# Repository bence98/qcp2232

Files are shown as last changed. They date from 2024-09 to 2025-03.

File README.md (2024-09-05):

# QCP2232HV USB-to-Quad UART

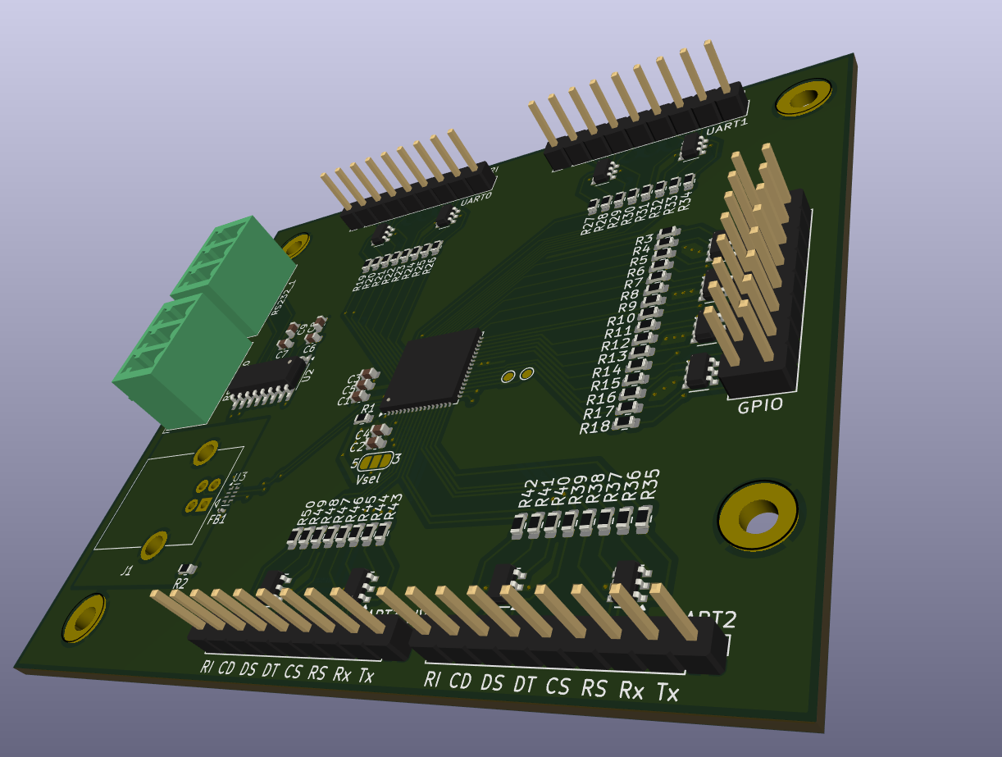
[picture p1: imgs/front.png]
Front side

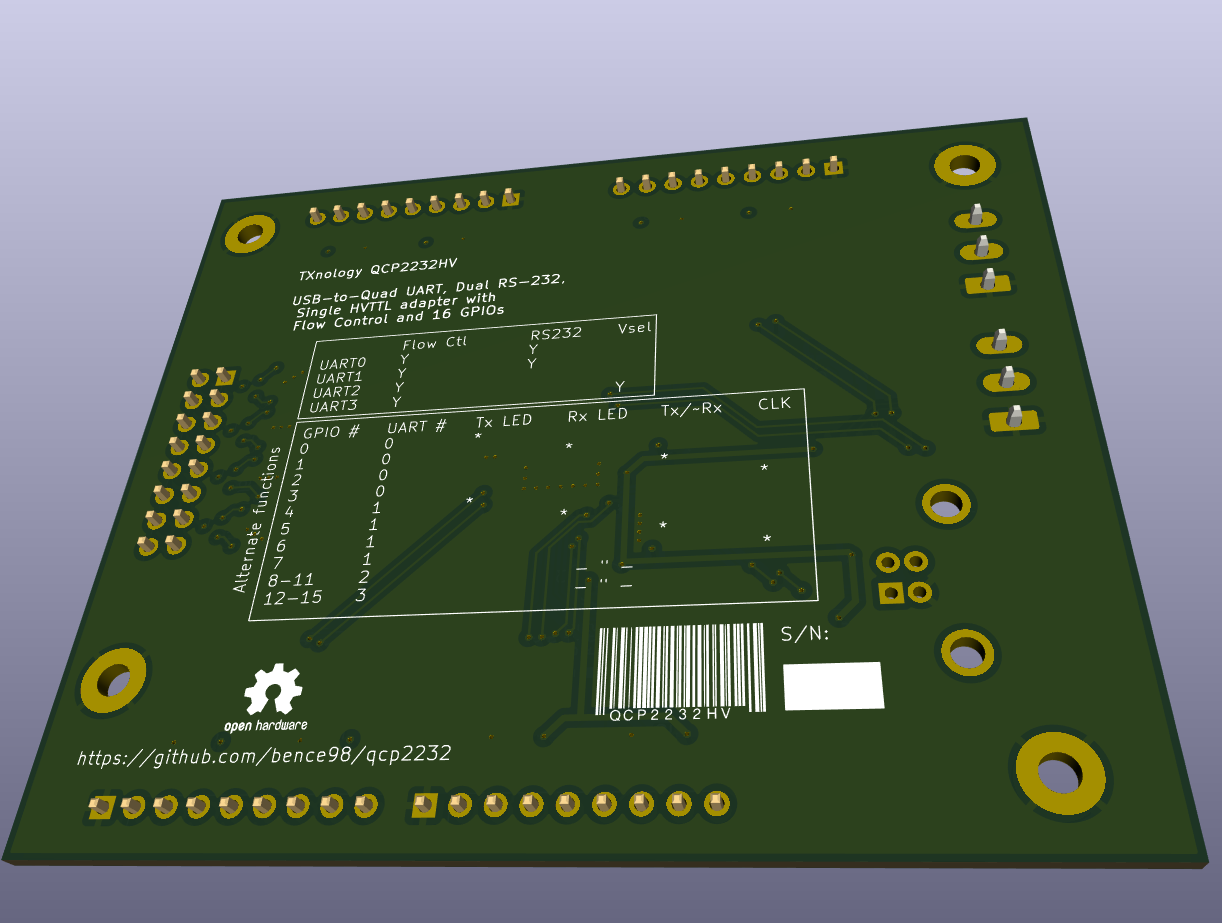
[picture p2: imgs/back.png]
Back side


## Features

4 TTL UARTs with full Flow Control
* Tx, Rx full duplex
* RTS/CTS (Request-/Clear-to-Send), DTR/DSR (Data Terminal/Set Ready)
* DCD (Data Carrier Detect), RI (Ring Indicator) inputs
* all pins ESD protected
  * full TVS diode protection
  * overcurrent limiting resistors
* see pinout at the end of the section

UART0 and UART1 have RS-232 option
* only Tx/Rx
* separate industrial connector
  * Phoenix MCV 1,5 G-3.81
  * Würth WR-TBL 321

UART3 has selectable TTL voltage (`Vsel`)
* 5V from USB or 3.3V from internal regulator
* UART0-2 are 3.3V

USB Type-B connector
* superior mechanical stability compared to Micro-B
* easier to handle than Mini-B
* more economical to produce than Type-C
* added noise immunity thanks to EMI suppression circuitry
* supports USB suspend mode

16 GPIOs
* 3.3V digital I/O
* all pins ESD protected
  * full TVS diode protection
  * overcurrent limiting resistors
* alternate functions, see table below
  * Tx, Rx LED: blinks on data transfer
  * Tx mode: for half duplex bus drivers eg. RS-485
  * clock: USART bit clock
* configurable via Silicon Labs' toolchain

| GPIO # | UART # | function |
|---|---|---|
| 0 | 0 | Tx LED |
| 1 | 0 | Rx LED |
| 2 | 0 |  Tx mode |
| 3 | 0 | clock |
| 4 | 1 | Tx LED |
| 5 | 1 | Rx LED |
| 6 | 1 |  Tx mode |
| 7 | 1 | clock |
| 8 | 2 | Tx LED |
| 9 | 2 | Rx LED |
| 10 | 2 |  Tx mode |
| 11 | 2 | clock |
| 12 | 3 | Tx LED |
| 13 | 3 | Rx LED |
| 14 | 3 |  Tx mode |
| 15 | 3 | clock |

Pinout (UARTs):

| | GND | TX  | RX | RTS | CTS | DTR | DSR | DCD | RI |
|---|-----|-----|----|-----|-----|-----|-----|-----|----|
| Label on board | | Tx  | Rx | RS  | CS  | DT  | DS  | CD  | RI |
| Direction | N/A | Out | In | Out | In  | Out | In  | In  | In |

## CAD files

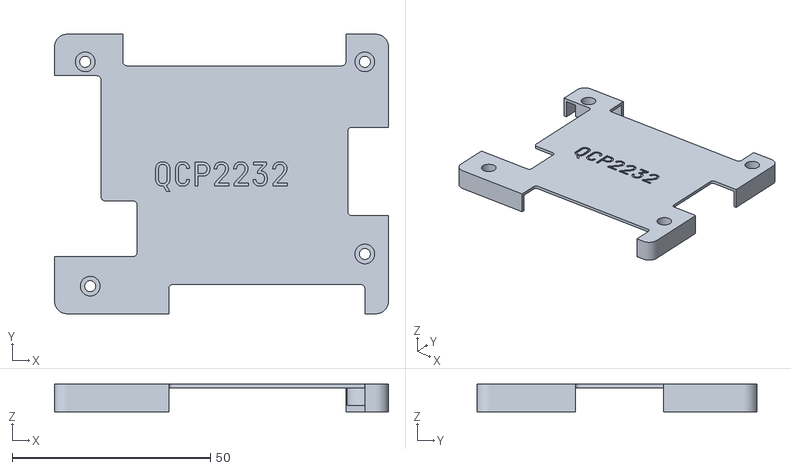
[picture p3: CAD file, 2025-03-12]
case/QCP2232 v5 top.stl
84.3 x 70.6 x 7.00

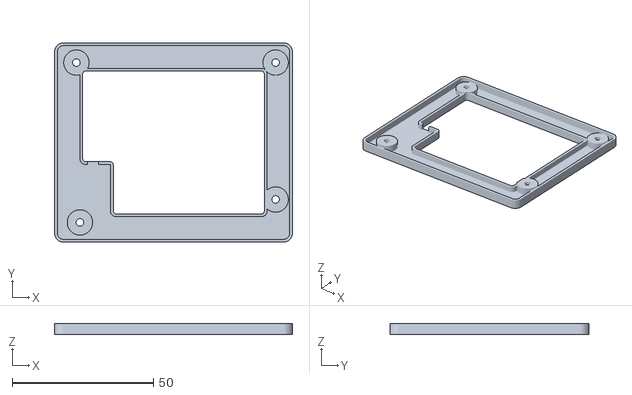
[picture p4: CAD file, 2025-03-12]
case/QCP2232 v5 bottom.stl
84.3 x 70.6 x 4.00

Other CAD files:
case/QCP2232 v6.f3z

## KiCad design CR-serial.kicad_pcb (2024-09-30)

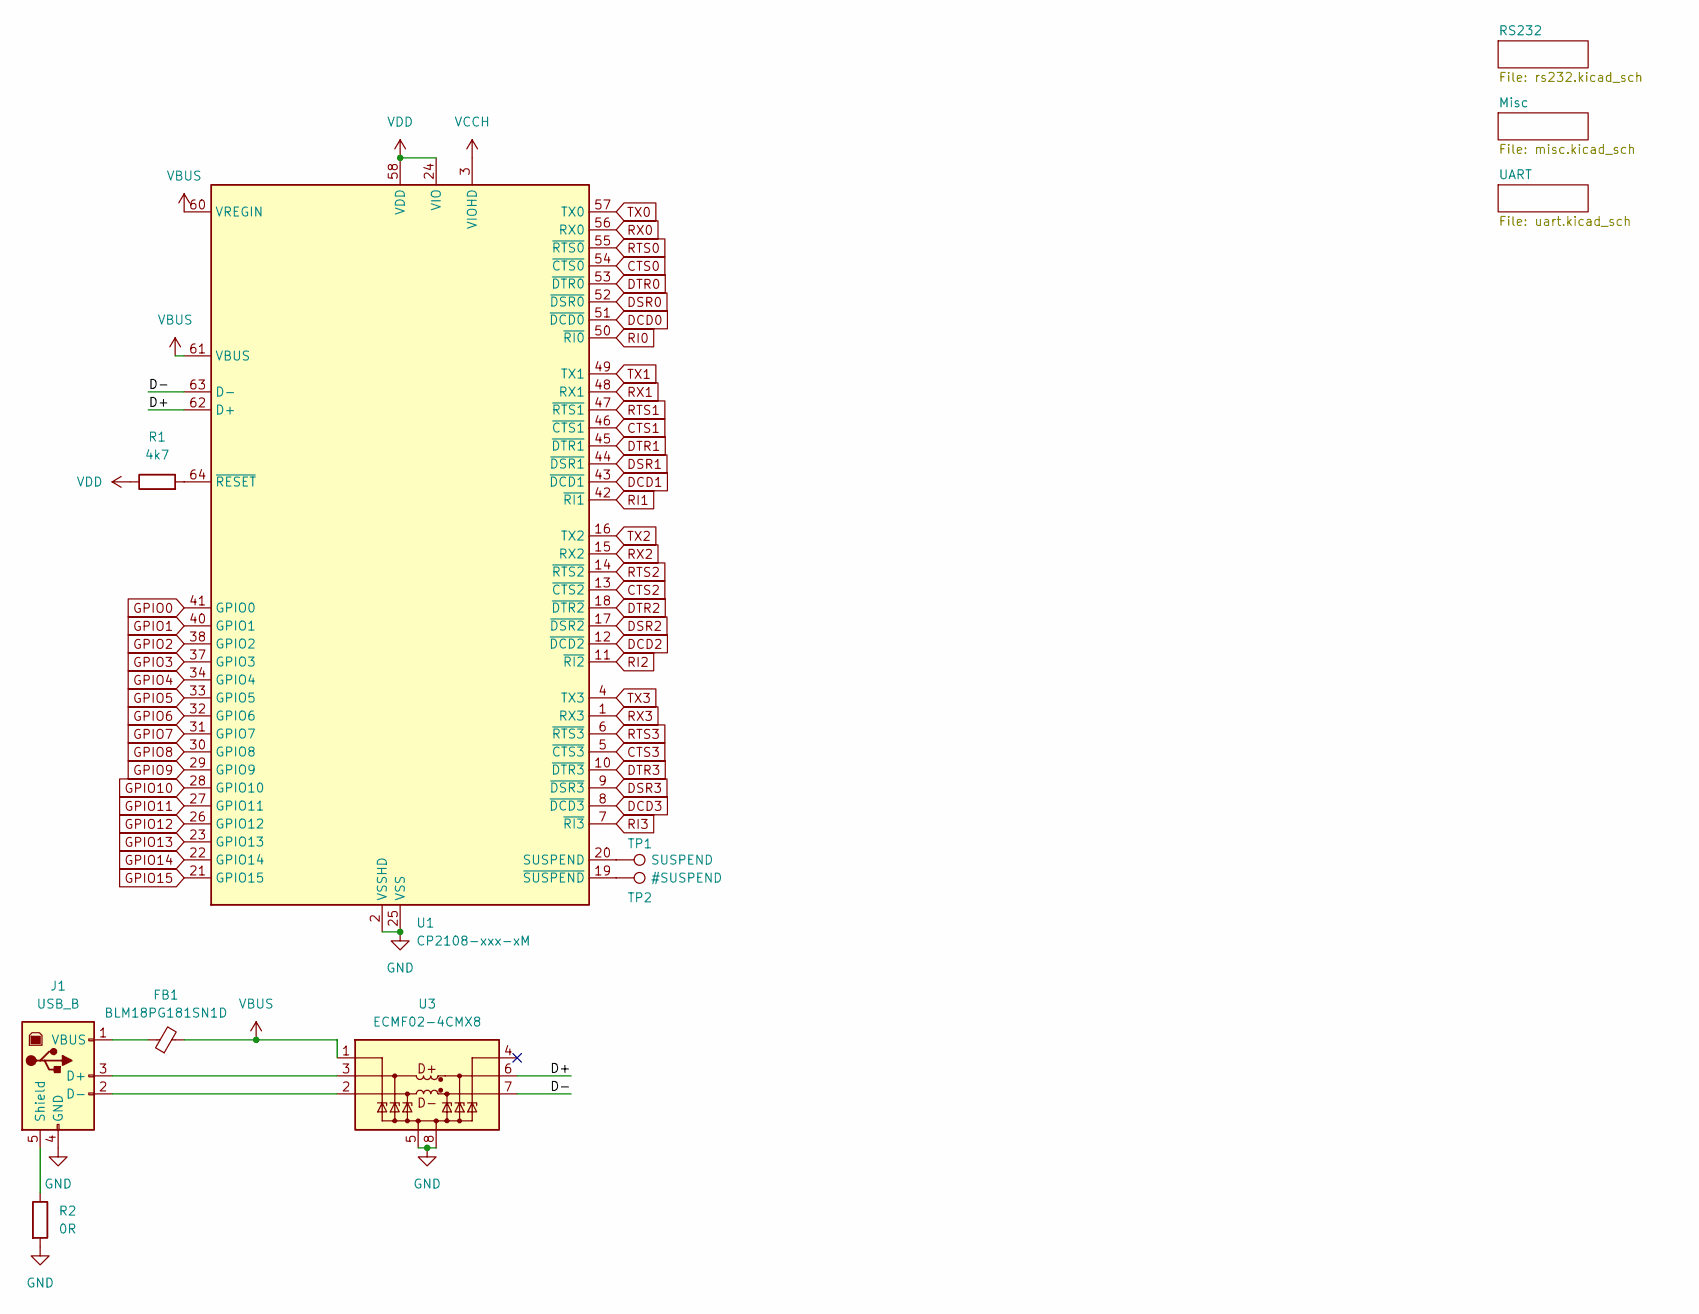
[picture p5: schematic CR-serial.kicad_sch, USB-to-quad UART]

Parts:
FB1: BLM18PG181SN1D; L_0603_1608Metric
J1: USB_B; USB_B_OST_USB-B1HSxx_Horizontal
R1: 4k7; R_0603_1608Metric
R2: 0R; R_0603_1608Metric
TP1: SUSPEND; TestPoint_Pad_D1.0mm
TP2: #SUSPEND; TestPoint_Pad_D1.0mm
U1: CP2108-xxx-xM; QFN-64-1EP_9x9mm_P0.5mm_EP4.1x4.1mm
U3: ECMF02-4CMX8; ST_UQFN-8L_1.15x2.45mm_P0.5mm

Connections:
/D+: U1.62 (D+), U3.6 (D+_out)
/D-: U1.63 (D-), U3.7 (D-_out)
CTS0: U1.54 (~CTS0); also elsewhere on the board
CTS1: U1.46 (~CTS1); also elsewhere on the board
CTS2: U1.13 (~CTS2); also elsewhere on the board
CTS3: U1.5 (~CTS3); also elsewhere on the board
DCD0: U1.51 (~DCD0); also elsewhere on the board
DCD1: U1.43 (~DCD1); also elsewhere on the board
DCD2: U1.12 (~DCD2); also elsewhere on the board
DCD3: U1.8 (~DCD3); also elsewhere on the board
DSR0: U1.52 (~DSR0); also elsewhere on the board
DSR1: U1.44 (~DSR1); also elsewhere on the board
DSR2: U1.17 (~DSR2); also elsewhere on the board
DSR3: U1.9 (~DSR3); also elsewhere on the board
DTR0: U1.53 (~DTR0); also elsewhere on the board
DTR1: U1.45 (~DTR1); also elsewhere on the board
DTR2: U1.18 (~DTR2); also elsewhere on the board
DTR3: U1.10 (~DTR3); also elsewhere on the board
GND: J1.4 (GND), R2.2, U1.2 (VSSHD), U1.25 (VSS), U1.59 (VSS), U1.65 (VSS), U3.5 (GND), U3.8 (GND); also elsewhere on the board
GPIO0: U1.41 (GPIO0); also elsewhere on the board
GPIO1: U1.40 (GPIO1); also elsewhere on the board
GPIO2: U1.38 (GPIO2); also elsewhere on the board
GPIO3: U1.37 (GPIO3); also elsewhere on the board
GPIO4: U1.34 (GPIO4); also elsewhere on the board
GPIO5: U1.33 (GPIO5); also elsewhere on the board
GPIO6: U1.32 (GPIO6); also elsewhere on the board
GPIO7: U1.31 (GPIO7); also elsewhere on the board
GPIO8: U1.30 (GPIO8); also elsewhere on the board
GPIO9: U1.29 (GPIO9); also elsewhere on the board
GPIO10: U1.28 (GPIO10); also elsewhere on the board
GPIO11: U1.27 (GPIO11); also elsewhere on the board
GPIO12: U1.26 (GPIO12); also elsewhere on the board
GPIO13: U1.23 (GPIO13); also elsewhere on the board
GPIO14: U1.22 (GPIO14); also elsewhere on the board
GPIO15: U1.21 (GPIO15); also elsewhere on the board
unnamed: J1.3 (D+), U3.3 (D+_in)
unnamed: J1.2 (D-), U3.2 (D-_in)
unnamed: J1.5 (Shield), R2.1
unnamed: FB1.1, J1.1 (VBUS)
unnamed: TP1.1, U1.20 (SUSPEND)
unnamed: R1.2, U1.64 (~RESET)
unnamed: TP2.1, U1.19 (~SUSPEND)
RI0: U1.50 (~RI0); also elsewhere on the board
RI1: U1.42 (~RI1); also elsewhere on the board
RI2: U1.11 (~RI2); also elsewhere on the board
RI3: U1.7 (~RI3); also elsewhere on the board
RTS0: U1.55 (~RTS0); also elsewhere on the board
RTS1: U1.47 (~RTS1); also elsewhere on the board
RTS2: U1.14 (~RTS2); also elsewhere on the board
RTS3: U1.6 (~RTS3); also elsewhere on the board
RX0: U1.56 (RX0); also elsewhere on the board
RX1: U1.48 (RX1); also elsewhere on the board
RX2: U1.15 (RX2); also elsewhere on the board
RX3: U1.1 (RX3); also elsewhere on the board
TX0: U1.57 (TX0); also elsewhere on the board
TX1: U1.49 (TX1); also elsewhere on the board
TX2: U1.16 (TX2); also elsewhere on the board
TX3: U1.4 (TX3); also elsewhere on the board
VBUS: FB1.2, U1.60 (VREGIN), U1.61 (VBUS), U3.1 (VBUS); also elsewhere on the board
VCCH: U1.3 (VIOHD); also elsewhere on the board
VDD: R1.1, U1.24 (VIO), U1.39 (VIO), U1.58 (VDD); also elsewhere on the board

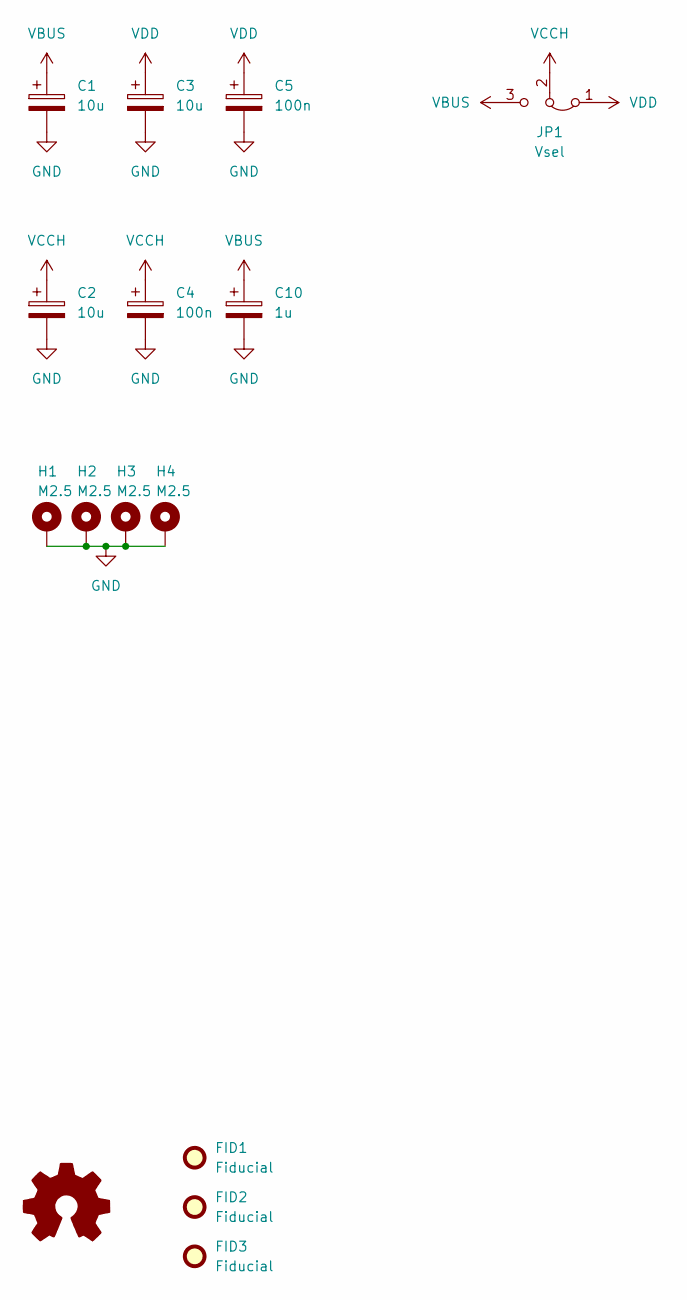
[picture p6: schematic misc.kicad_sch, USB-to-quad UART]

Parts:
C1, C2, C3: 10u; C_0603_1608Metric
C4, C5: 100n; C_0603_1608Metric
C10: 1u; C_0603_1608Metric
FID1, FID2, FID3: Fiducial; Fiducial_Cross_0.5mm_Mask2mm
H1, H2, H3, H4: M2.5; MountingHole_2.7mm_M2.5_Pad
JP1: Vsel; SolderJumper-3_P1.3mm_Bridged12_RoundedPad1.0x1.5mm_NumberL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
SYM1: Logo_Open_Hardware_Small; OSHW-Logo2_7.3x6mm_SilkScreen

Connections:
GND: C1.2, C2.2, C3.2, C4.2, C5.2, C10.2, H1.1, H2.1, H3.1, H4.1; also elsewhere on the board
VBUS: C1.1, C10.1, JP1.3 (B); also elsewhere on the board
VCCH: C2.1, C4.1, JP1.2 (C); also elsewhere on the board
VDD: C3.1, C5.1, JP1.1 (A); also elsewhere on the board

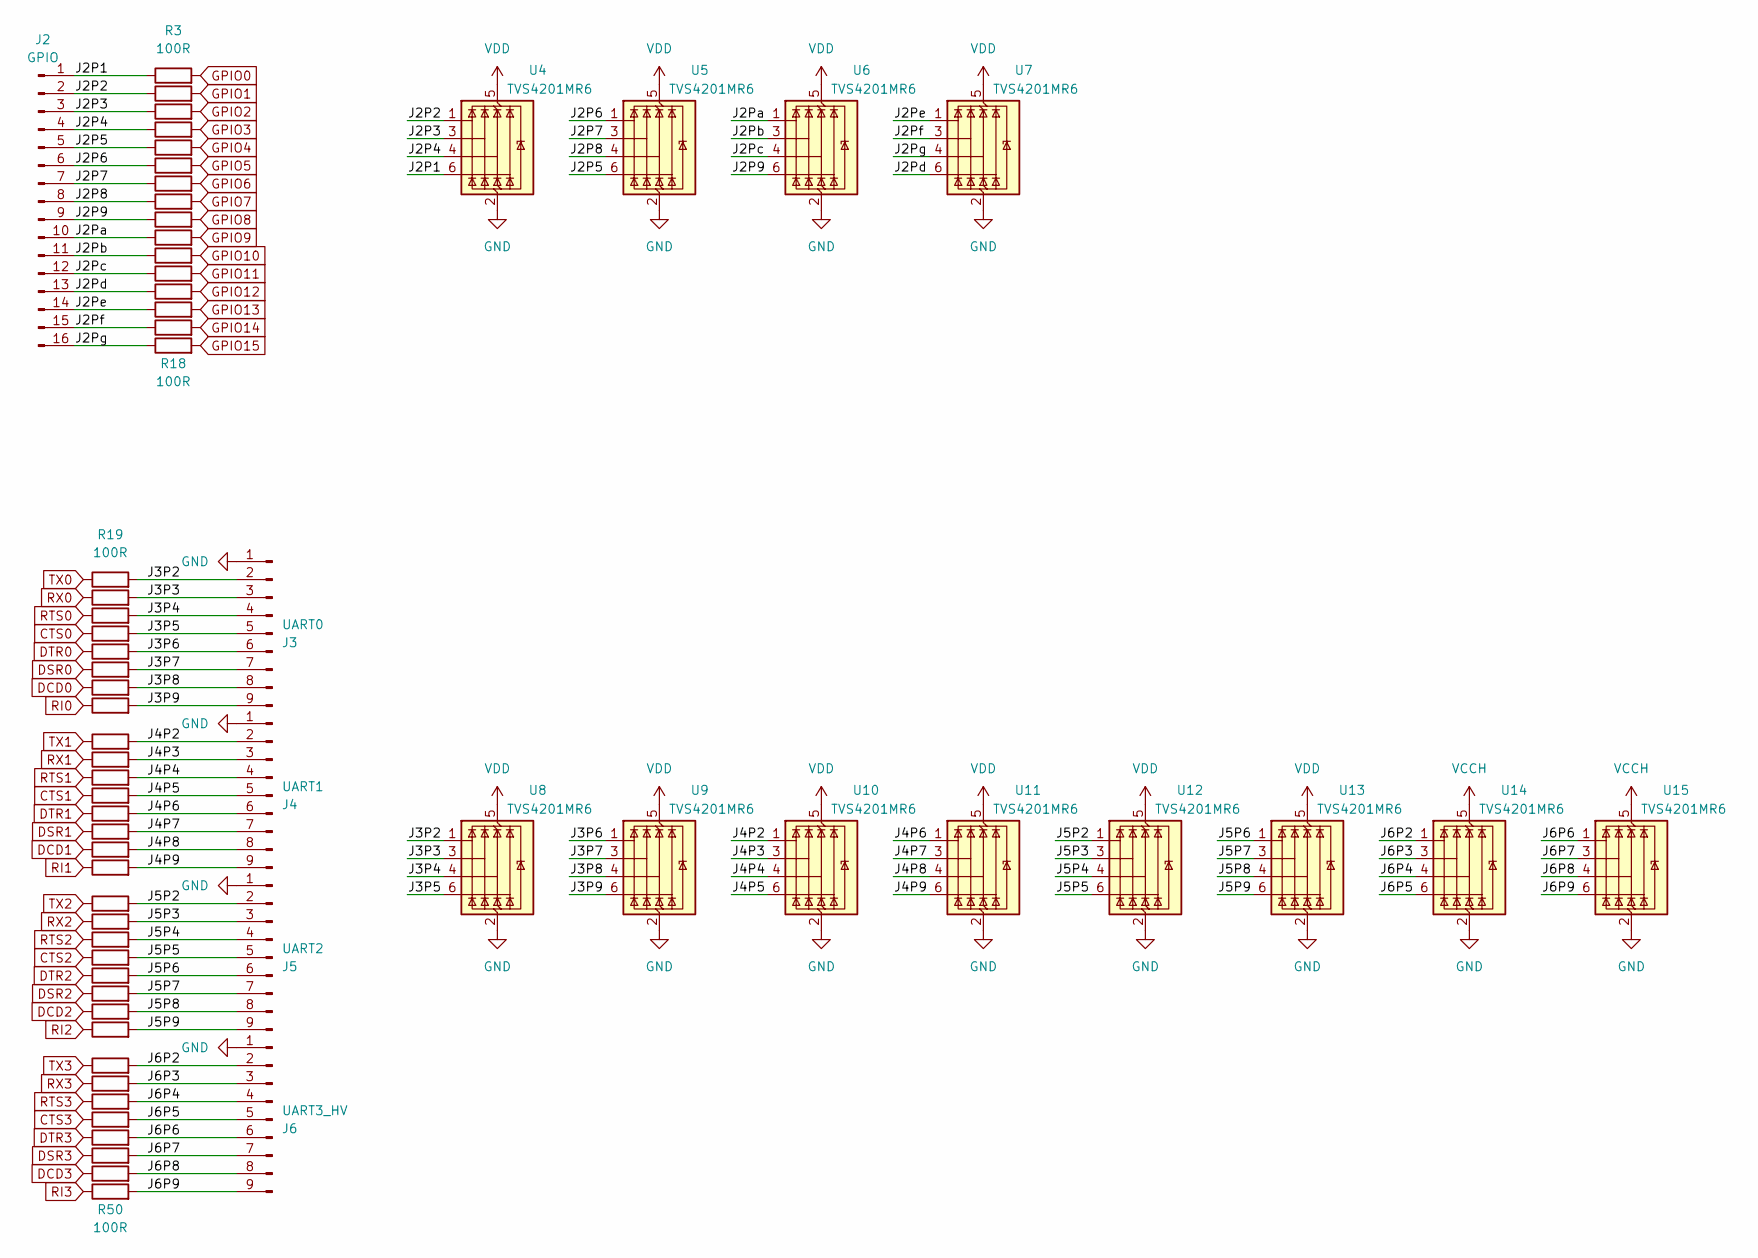
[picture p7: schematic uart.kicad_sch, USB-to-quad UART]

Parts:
J2: GPIO; PinHeader_2x08_P2.54mm_Vertical
J3: UART0; PinHeader_1x09_P2.54mm_Vertical
J4: UART1; PinHeader_1x09_P2.54mm_Vertical
J5: UART2; PinHeader_1x09_P2.54mm_Vertical
J6: UART3_HV; PinHeader_1x09_P2.54mm_Vertical
R3, R4, R5, R6, R7, R8, R9, R10, R11, R12, R13, R14, R15, R16, R17, R18, R19, R20, R21, R22, R23, R24, R25, R26, R27, R28, R29, R30, R31, R32, R33, R34, R35, R36, R37, R38, R39, R40, R41, R42, R43, R44, R45, R46, R47, R48, R49, R50: 100R; R_0603_1608Metric
U4, U5, U6, U7, U8, U9, U10, U11, U12, U13, U14, U15: TVS4201MR6; TSOP-6_1.65x3.05mm_P0.95mm

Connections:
/UART/J2P1: J2.1, R3.1, U4.6 (I/O4)
/UART/J2P2: J2.2, R4.1, U4.1 (I/O1)
/UART/J2P3: J2.3, R5.1, U4.3 (I/O2)
/UART/J2P4: J2.4, R6.1, U4.4 (I/O3)
/UART/J2P5: J2.5, R7.1, U5.6 (I/O4)
/UART/J2P6: J2.6, R8.1, U5.1 (I/O1)
/UART/J2P7: J2.7, R9.1, U5.3 (I/O2)
/UART/J2P8: J2.8, R10.1, U5.4 (I/O3)
/UART/J2P9: J2.9, R11.1, U6.6 (I/O4)
/UART/J2Pa: J2.10, R12.1, U6.1 (I/O1)
/UART/J2Pb: J2.11, R13.1, U6.3 (I/O2)
/UART/J2Pc: J2.12, R14.1, U6.4 (I/O3)
/UART/J2Pd: J2.13, R15.1, U7.6 (I/O4)
/UART/J2Pe: J2.14, R16.1, U7.1 (I/O1)
/UART/J2Pf: J2.15, R17.1, U7.3 (I/O2)
/UART/J2Pg: J2.16, R18.1, U7.4 (I/O3)
/UART/J3P2: J3.2, R19.2, U8.1 (I/O1)
/UART/J3P3: J3.3, R20.2, U8.3 (I/O2)
/UART/J3P4: J3.4, R21.2, U8.4 (I/O3)
/UART/J3P5: J3.5, R22.2, U8.6 (I/O4)
/UART/J3P6: J3.6, R23.2, U9.1 (I/O1)
/UART/J3P7: J3.7, R24.2, U9.3 (I/O2)
/UART/J3P8: J3.8, R25.2, U9.4 (I/O3)
/UART/J3P9: J3.9, R26.2, U9.6 (I/O4)
/UART/J4P2: J4.2, R27.2, U10.1 (I/O1)
/UART/J4P3: J4.3, R28.2, U10.3 (I/O2)
/UART/J4P4: J4.4, R29.2, U10.4 (I/O3)
/UART/J4P5: J4.5, R30.2, U10.6 (I/O4)
/UART/J4P6: J4.6, R31.2, U11.1 (I/O1)
/UART/J4P7: J4.7, R32.2, U11.3 (I/O2)
/UART/J4P8: J4.8, R33.2, U11.4 (I/O3)
/UART/J4P9: J4.9, R34.2, U11.6 (I/O4)
/UART/J5P2: J5.2, R35.2, U12.1 (I/O1)
/UART/J5P3: J5.3, R36.2, U12.3 (I/O2)
/UART/J5P4: J5.4, R37.2, U12.4 (I/O3)
/UART/J5P5: J5.5, R38.2, U12.6 (I/O4)
/UART/J5P6: J5.6, R39.2, U13.1 (I/O1)
/UART/J5P7: J5.7, R40.2, U13.3 (I/O2)
/UART/J5P8: J5.8, R41.2, U13.4 (I/O3)
/UART/J5P9: J5.9, R42.2, U13.6 (I/O4)
/UART/J6P2: J6.2, R43.2, U14.1 (I/O1)
/UART/J6P3: J6.3, R44.2, U14.3 (I/O2)
/UART/J6P4: J6.4, R45.2, U14.4 (I/O3)
/UART/J6P5: J6.5, R46.2, U14.6 (I/O4)
/UART/J6P6: J6.6, R47.2, U15.1 (I/O1)
/UART/J6P7: J6.7, R48.2, U15.3 (I/O2)
/UART/J6P8: J6.8, R49.2, U15.4 (I/O3)
/UART/J6P9: J6.9, R50.2, U15.6 (I/O4)
CTS0: R22.1; also elsewhere on the board
CTS1: R30.1; also elsewhere on the board
CTS2: R38.1; also elsewhere on the board
CTS3: R46.1; also elsewhere on the board
DCD0: R25.1; also elsewhere on the board
DCD1: R33.1; also elsewhere on the board
DCD2: R41.1; also elsewhere on the board
DCD3: R49.1; also elsewhere on the board
DSR0: R24.1; also elsewhere on the board
DSR1: R32.1; also elsewhere on the board
DSR2: R40.1; also elsewhere on the board
DSR3: R48.1; also elsewhere on the board
DTR0: R23.1; also elsewhere on the board
DTR1: R31.1; also elsewhere on the board
DTR2: R39.1; also elsewhere on the board
DTR3: R47.1; also elsewhere on the board
GND: J3.1, J4.1, J5.1, J6.1, U4.2 (GND), U5.2 (GND), U6.2 (GND), U7.2 (GND), U8.2 (GND), U9.2 (GND), U10.2 (GND), U11.2 (GND), U12.2 (GND), U13.2 (GND), U14.2 (GND), U15.2 (GND); also elsewhere on the board
GPIO0: R3.2; also elsewhere on the board
GPIO1: R4.2; also elsewhere on the board
GPIO2: R5.2; also elsewhere on the board
GPIO3: R6.2; also elsewhere on the board
GPIO4: R7.2; also elsewhere on the board
GPIO5: R8.2; also elsewhere on the board
GPIO6: R9.2; also elsewhere on the board
GPIO7: R10.2; also elsewhere on the board
GPIO8: R11.2; also elsewhere on the board
GPIO9: R12.2; also elsewhere on the board
GPIO10: R13.2; also elsewhere on the board
GPIO11: R14.2; also elsewhere on the board
GPIO12: R15.2; also elsewhere on the board
GPIO13: R16.2; also elsewhere on the board
GPIO14: R17.2; also elsewhere on the board
GPIO15: R18.2; also elsewhere on the board
RI0: R26.1; also elsewhere on the board
RI1: R34.1; also elsewhere on the board
RI2: R42.1; also elsewhere on the board
RI3: R50.1; also elsewhere on the board
RTS0: R21.1; also elsewhere on the board
RTS1: R29.1; also elsewhere on the board
RTS2: R37.1; also elsewhere on the board
RTS3: R45.1; also elsewhere on the board
RX0: R20.1; also elsewhere on the board
RX1: R28.1; also elsewhere on the board
RX2: R36.1; also elsewhere on the board
RX3: R44.1; also elsewhere on the board
TX0: R19.1; also elsewhere on the board
TX1: R27.1; also elsewhere on the board
TX2: R35.1; also elsewhere on the board
TX3: R43.1; also elsewhere on the board
VCCH: U14.5 (VBUS), U15.5 (VBUS); also elsewhere on the board
VDD: U4.5 (VBUS), U5.5 (VBUS), U6.5 (VBUS), U7.5 (VBUS), U8.5 (VBUS), U9.5 (VBUS), U10.5 (VBUS), U11.5 (VBUS), U12.5 (VBUS), U13.5 (VBUS); also elsewhere on the board

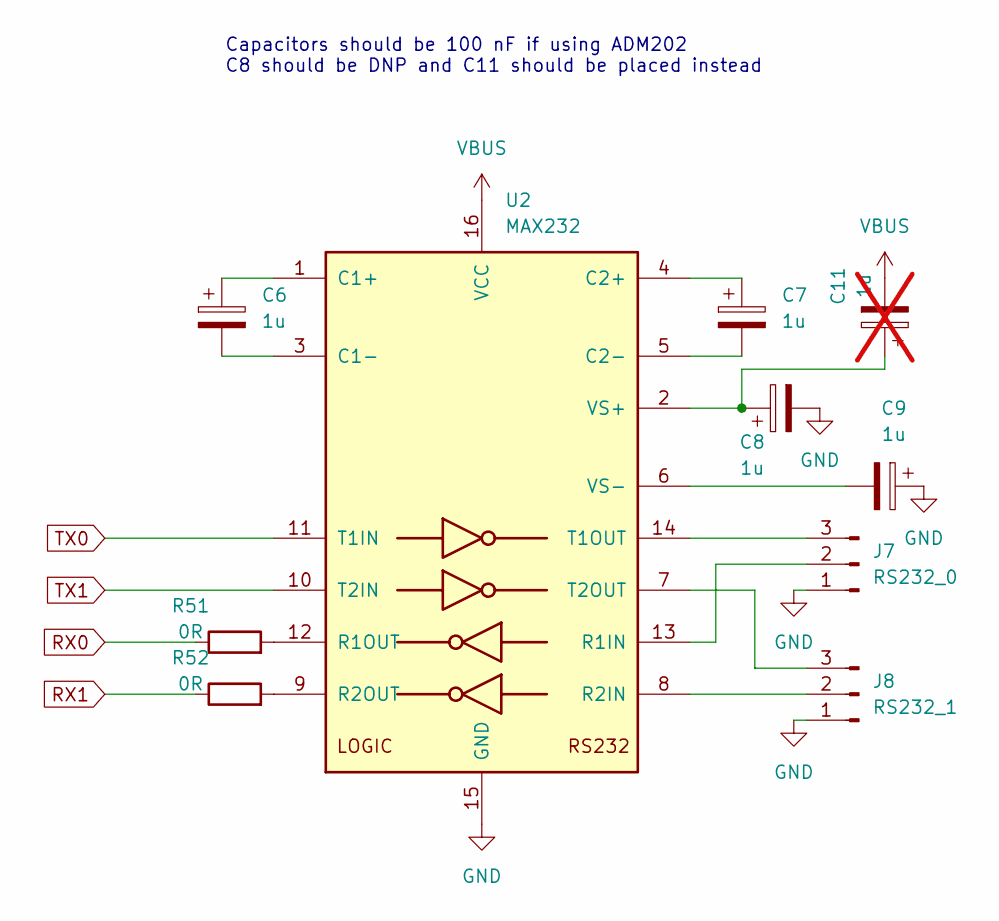
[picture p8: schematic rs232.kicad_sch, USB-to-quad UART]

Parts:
C6, C7, C8, C9: 1u; C_0603_1608Metric
C11: 1u; C_0603_1608Metric; not fitted
J7: RS232_0; PhoenixContact_MCV_1,5_3-G-3.81_1x03_P3.81mm_Vertical
J8: RS232_1; PhoenixContact_MCV_1,5_3-G-3.81_1x03_P3.81mm_Vertical
R51, R52: 0R; R_0603_1608Metric
U2: MAX232; SOIC-16_3.9x9.9mm_P1.27mm

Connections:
GND: C8.2, C9.1, J7.1, J8.1, U2.15 (GND); also elsewhere on the board
unnamed: J7.2, U2.13 (R1IN)
unnamed: J7.3, U2.14 (T1OUT)
unnamed: J8.2, U2.8 (R2IN)
unnamed: J8.3, U2.7 (T2OUT)
unnamed: C6.1, U2.1 (C1+)
unnamed: C6.2, U2.3 (C1-)
unnamed: C7.1, U2.4 (C2+)
unnamed: C7.2, U2.5 (C2-)
unnamed: R51.2, U2.12 (R1OUT)
unnamed: R52.2, U2.9 (R2OUT)
unnamed: C8.1, C11.1, U2.2 (VS+)
unnamed: C9.2, U2.6 (VS-)
RX0: R51.1; also elsewhere on the board
RX1: R52.1; also elsewhere on the board
TX0: U2.11 (T1IN); also elsewhere on the board
TX1: U2.10 (T2IN); also elsewhere on the board
VBUS: C11.2, U2.16 (VCC); also elsewhere on the board

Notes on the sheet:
Capacitors should be 100 nF if using ADM202 C8 should be DNP and C11 should be placed instead

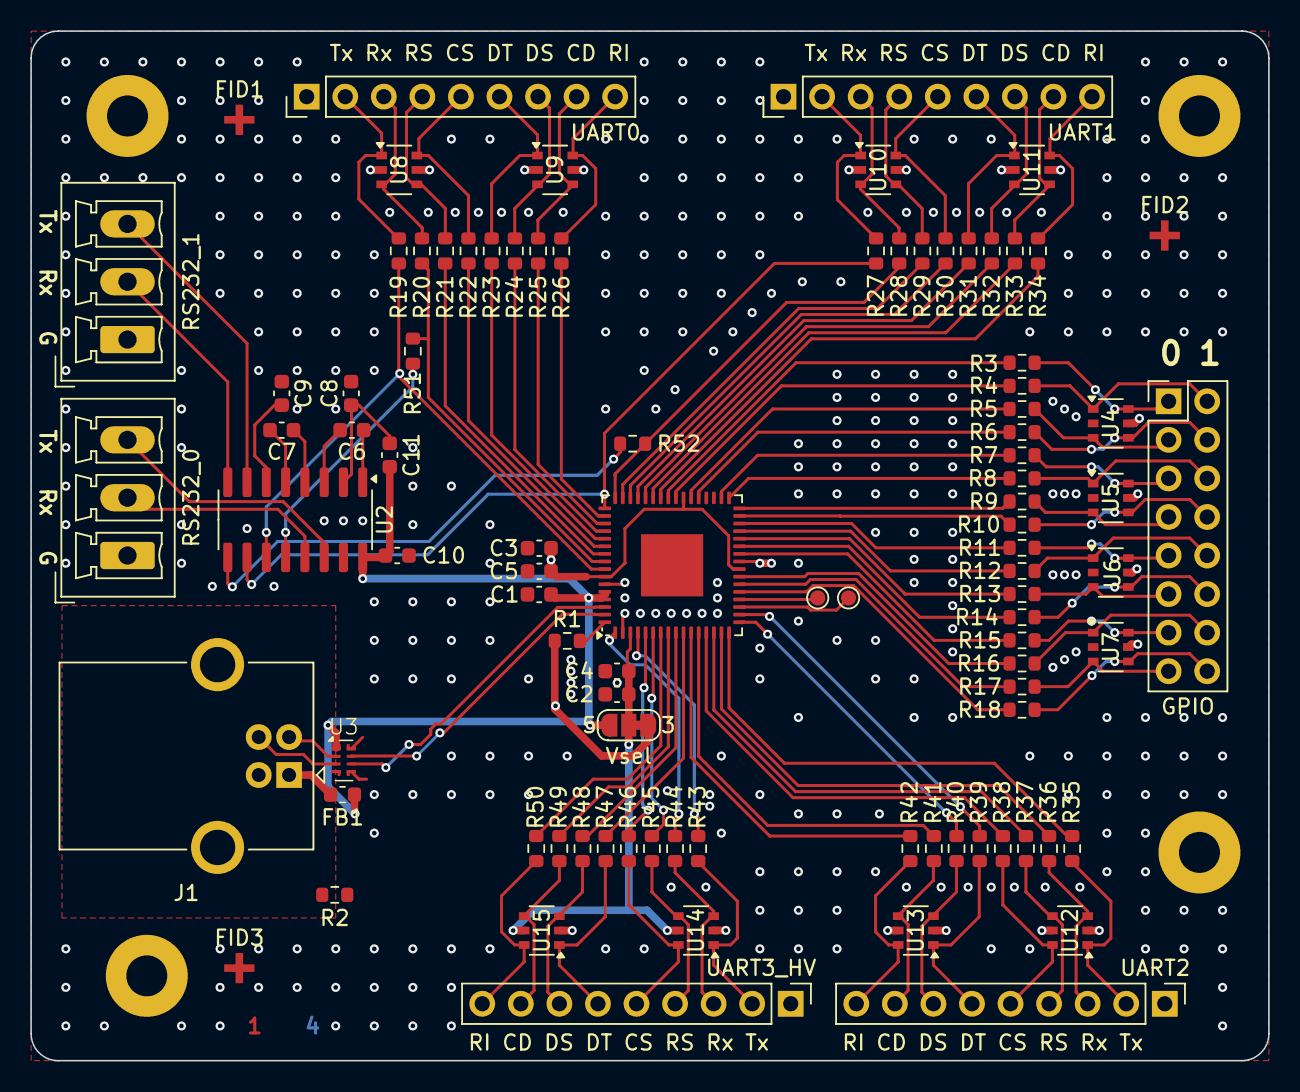
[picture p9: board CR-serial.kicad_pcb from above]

Board: 4 copper layers, 81.5 x 67.8 mm, 98 parts (1 on the bottom side), 121 nets.

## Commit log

2024-08-02 First revision: CP2108-based, fully routed
    [CR-serial.kicad_pcb, CR-serial.kicad_sch]
2024-08-05 Make GPIO header double-row
    [CR-serial.kicad_pcb, CR-serial.kicad_sch]
2024-08-05 Move UART1 header to the edge of the board
    [CR-serial.kicad_pcb]
2024-08-05 Hide unnecessary designators from F.Silk
    [CR-serial.kicad_pcb]
2024-08-09 Move UART0 connector around
    [CR-serial.kicad_pcb]
2024-08-09 Extend board, move UART2-3 around
    (Areas unfilled...)
    [CR-serial.kicad_pcb]
2024-08-13 Change RS232 connectors
    Zones filled again
    [CR-serial.kicad_pcb, CR-serial.kicad_sch]
2024-08-16 Add silkscreen markings
    `--patience` is recommended for viewing
    [CR-serial.kicad_pcb]
2024-08-26 Refactor UARTs: move GND next to TX/RX
    [CR-serial.kicad_sch]
2024-08-27 Add 0Rs on all CP2108 outputs
    `--patience` is recommended
    [CR-serial.kicad_sch]
2024-08-27 Change USB connector to USB-B
    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
    [CR-serial.kicad_sch]
2024-08-27 Change passives to 0603 size
    [CR-serial.kicad_sch]
2024-08-28 Change USB protection: add ECMF02-4CMX8
    [CR-serial.kicad_sch]
2024-08-29 UARTs: Rework ESD protection, use individual Rs, add TVS
    [CR-serial.kicad_sch]
2024-08-29 Refactor: split out RS-232 driver and misc components
    (e.g. bus capacitors, mounting holes)
    [CR-serial.kicad_sch, misc.kicad_sch, rs232.kicad_sch]
2024-08-30 Export common fields to all sheets
    [CR-serial.kicad_sch, misc.kicad_sch, rs232.kicad_sch]
2024-08-30 WIP: Refactor: split out UART headers to a new page
    [CR-serial.kicad_sch, uart.kicad_sch]
2024-08-30 Refactor: split out UART headers to a new page
    [CR-serial.kicad_sch, uart.kicad_sch]
2024-08-30 More and bigger screw holes
    [misc.kicad_sch]
2024-08-30 Bigger caps
    [misc.kicad_sch]
2024-08-30 Renumber TVS diodes' legs to ease PCB routing
    [uart.kicad_sch]
2024-09-03 New board
    * 4 layers: internal VDD, GND plane
    * connectors on board edge
    * MAX232 on top
    * product name on bottom
    * lots of (nested) groups
    * and of course, the schematic changes
    [CR-serial.kicad_pcb]
2024-09-04 More silkscreen work
    [CR-serial.kicad_pcb]
2024-09-04 Re-add OSHW logo, add GH URL, move caps
    [CR-serial.kicad_pcb, misc.kicad_sch]
2024-09-04 Round off corners
    [CR-serial.kicad_pcb]
2024-09-04 Stitch vias
    A lot... of... stitch vias...
    [CR-serial.kicad_pcb]
2024-09-05 PCB: add title
    [CR-serial.kicad_pcb]
2024-09-06 Library: Fix default footprint, add descriptions
2024-09-10 Group GND vias
    UUID list generated with:
    ```Bash
    git show 7479980e2907 --patience | grep -e "+.*uuid" | cut -d\" -f2
    ```
    [CR-serial.kicad_pcb]
2024-09-10 More GND vias
    [CR-serial.kicad_pcb]
2024-09-10 PCB: Add layer indicator
    [CR-serial.kicad_pcb]
2024-09-10 Add one more capacitor to VBUS
    [CR-serial.kicad_pcb, misc.kicad_sch]
2024-09-12 Add option for ADM202
    [CR-serial.kicad_pcb, rs232.kicad_sch]
2024-09-23 Change `.1u` to `100n` for clarity
    [misc.kicad_sch]
2024-09-23 Fix ferrite bead footprint
    [CR-serial.kicad_sch]
2024-09-23 Update PCB: fix ferrite and 100nF capacitors
    [CR-serial.kicad_pcb]
2024-09-24 Add RS232 RX enable for more flexibility
    [CR-serial.kicad_sch, misc.kicad_sch, rs232.kicad_sch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]
2024-09-30 PCB: Add RS232 RX enable resistors, unfill zones
    [CR-serial.kicad_pcb]
2024-09-30 Add fiducials
    [CR-serial.kicad_pcb, misc.kicad_sch]
2025-03-12 Case: Add STL and F3Z files of the first printed case
    Designed with Fusion 360
    [QCP2232 v5 bottom.stl, QCP2232 v5 top.stl, QCP2232 v6.f3z]
